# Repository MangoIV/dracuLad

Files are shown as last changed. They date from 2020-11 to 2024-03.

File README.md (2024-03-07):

# The DracuLad keyboard
This is a 34-36-key-board.
## Features
- 36 keys, two of them can be replaced by rotary encoders making it support 34-36 keys and 2-4 encoders. 
- bright RGB Underglow with WS2812b LEDs
- one SSD1306 OLED per side
- support for the [pimoroni trackball](https://shop.pimoroni.com/products/trackball-breakout)
- powered by QMK-firmware (Firmware has been merged and can be found on [the QMK master](https://github.com/qmk/qmk_firmware/))
- aggressive pinky stagger similar to the Kyria but with a slightly alternative thumb cluster to raise comfort for large hands
- support for MX and Kailh choc v1 switches
- files for fr4 plate and acrylic bottom plate as well as OLED window

## State of the project
- PCBs are fully working (OLED, LEDs, all switches, encoders, Trackball)
- acrylic plates have arrived and fit perfectly
- 3D-printable case has been added thanks to the awesome work of Sadek Baroudi
- basic ZMK Firmware (not all features implemented yet) exists on [my fork of the zmk firmware](https://github.com/MangoIV/zmk.git)

## Hardware availability
- hardware availability is always a big problem and ordering everything yourself is a big hustle. Therefore I'm happy to tell you that Ben from keycapsss (not me) is so kind [to offer everything to make a full build](https://keycapsss.com/). And for those of you who are American, [littlekeyboards](https://www.littlekeyboards.com/) (also not me) also offers kits
- if you live in a remote area resulting in high shipping costs or problems with importing, gerbers for ordering the PCBs and SVGs for getting plates cut are available in this repo, too

## Things to consider before getting a DracuLad
- for the upper encoder you can't use the really big guitar knobs as they're too wide and will interfere with the OLEDs, the smaller ones are recommended
- the thumb cluster is lower than on boards like the Corne keyboard
- liking or disliking a layout is not a matter of how "good" the layout is but mostly preference, hence I recommend looking at [a split keyboard comparison site](https://jhelvy.shinyapps.io/splitkbcompare/) and print out some layouts to confirm you like it. (DracuLad can be found there, too)
- before purchasing encoders, make sure they fit! The holes in the plate are 12mm x 12mm and won't fit bigger encoders. They're in particular not the size of the switch footprints.

## Some pictures to get your mouth watery
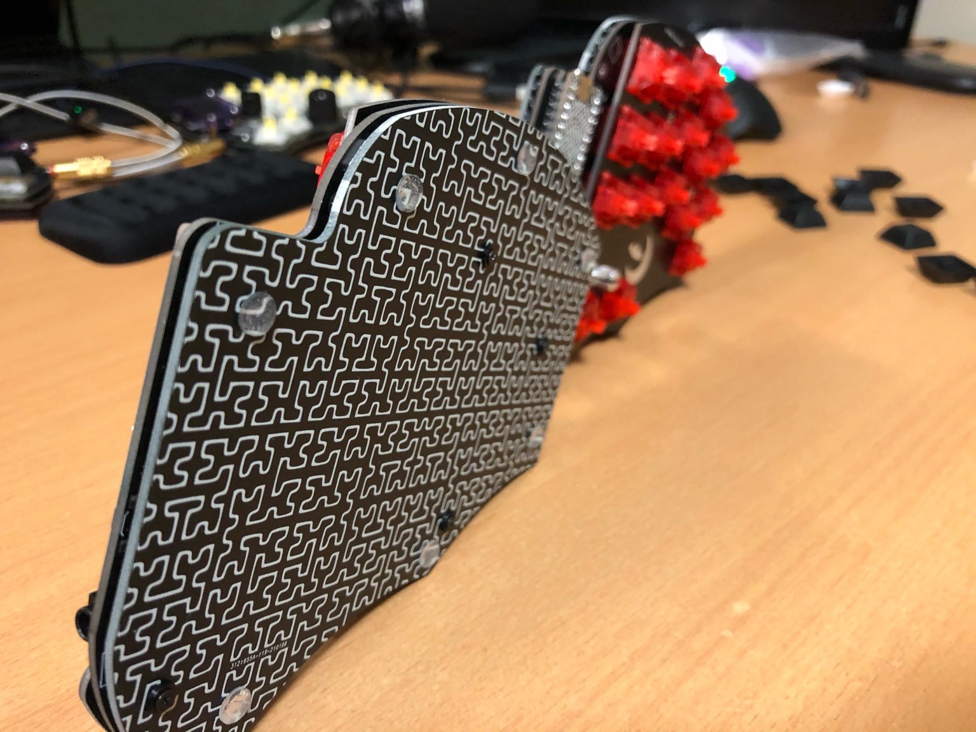
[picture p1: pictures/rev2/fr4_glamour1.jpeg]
glamour shot 1 pimoroni, fr4

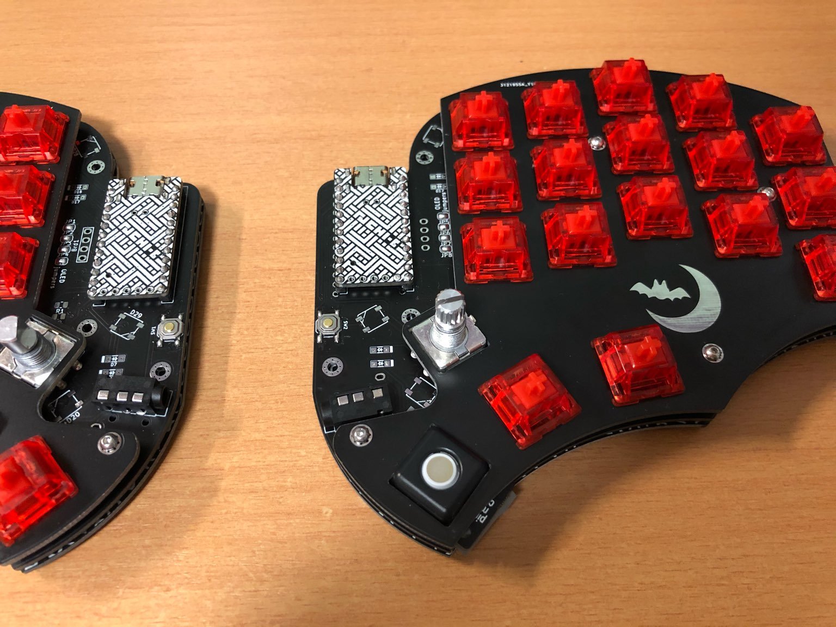
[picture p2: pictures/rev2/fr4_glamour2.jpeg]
glamour shot 1 pimoroni, fr4

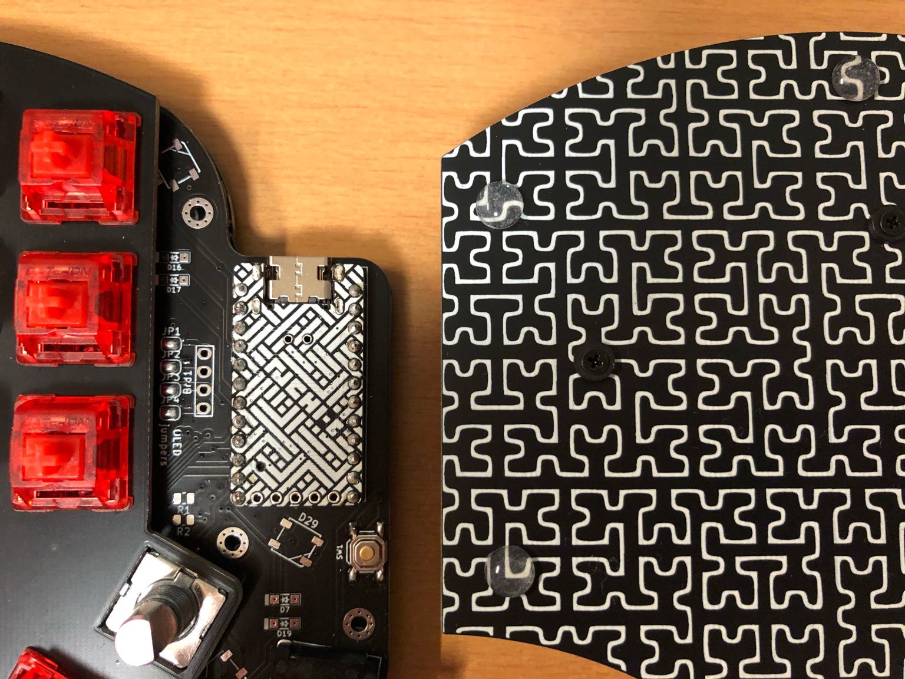
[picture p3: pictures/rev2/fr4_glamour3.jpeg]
glamour shot 1 pimoroni, fr4

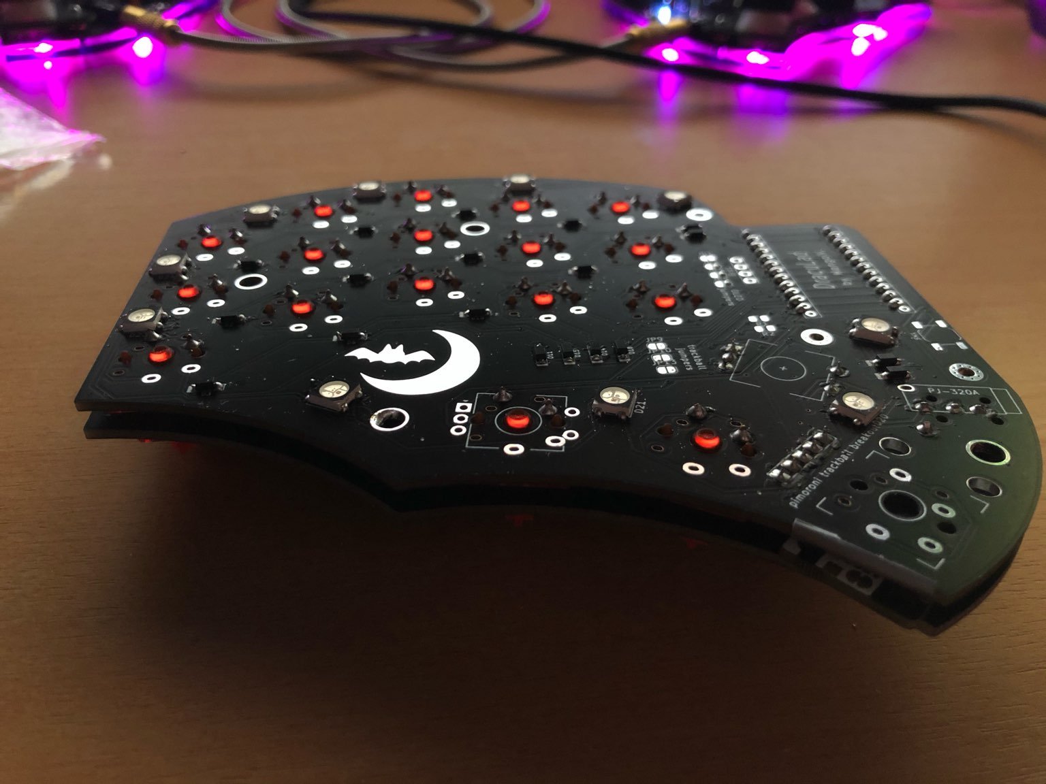
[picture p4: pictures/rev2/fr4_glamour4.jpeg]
glamour shot 1 pimoroni, fr4

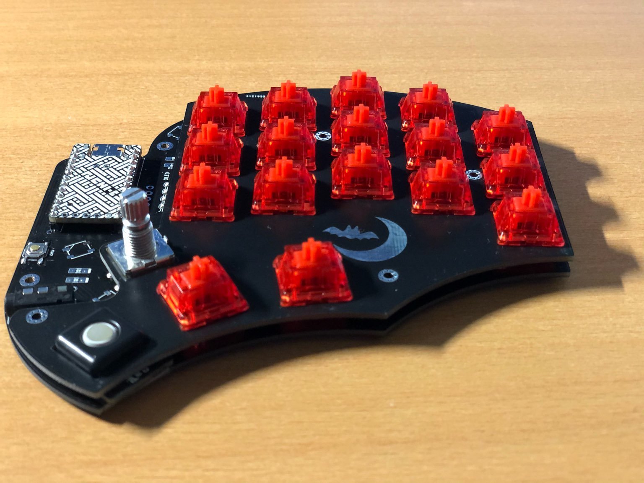
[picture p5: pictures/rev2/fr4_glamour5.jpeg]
glamour shot 1 pimoroni, fr4

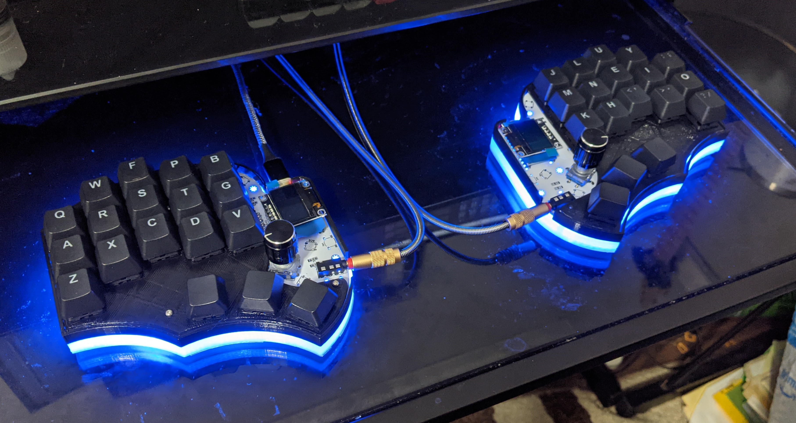
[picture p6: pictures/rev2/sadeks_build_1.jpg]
glamour shot of 3D printed High Pro case by Sadek Baroudi

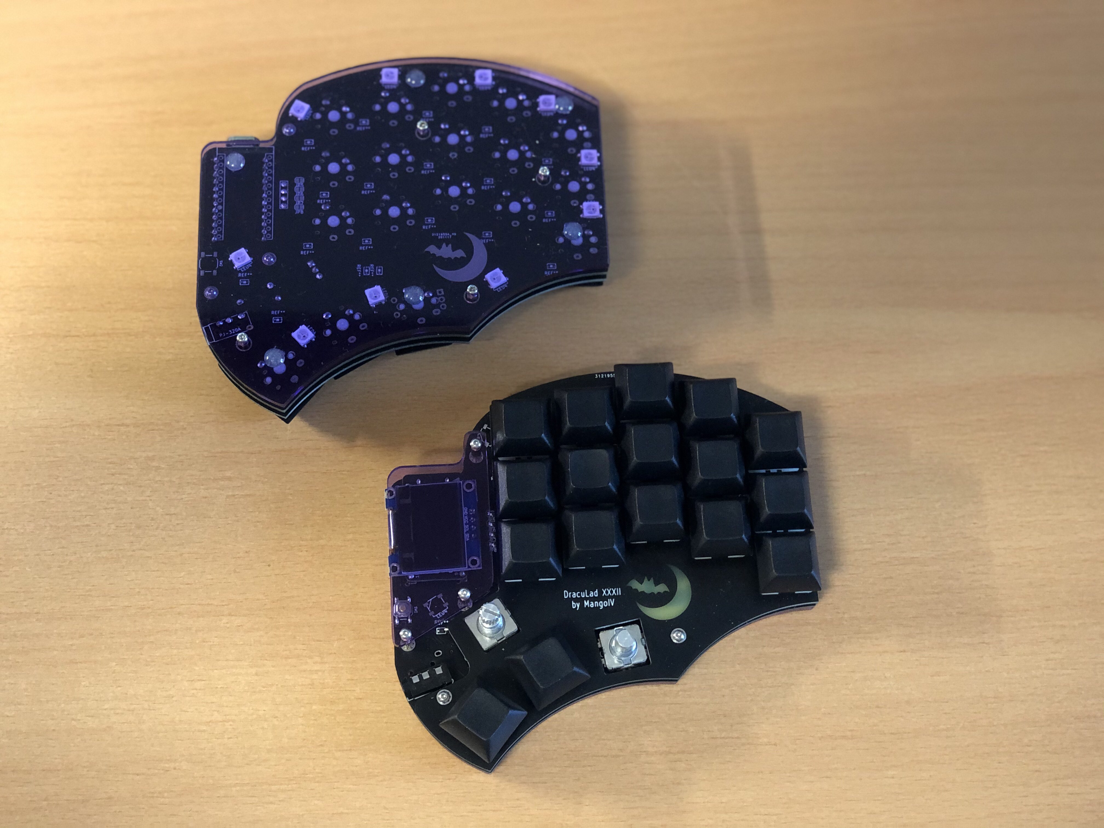
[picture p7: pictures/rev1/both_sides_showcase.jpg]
showcase of both sides

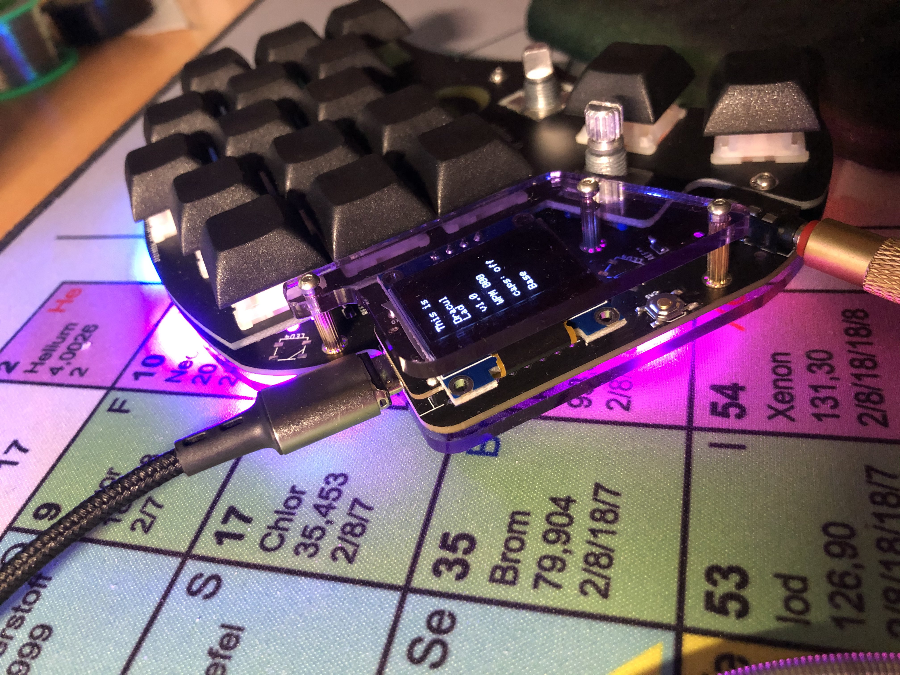
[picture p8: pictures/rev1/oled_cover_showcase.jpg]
showcase of oled cover

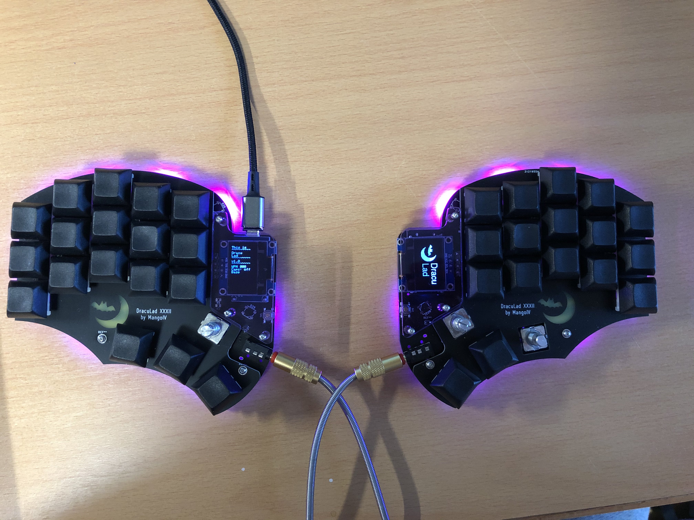
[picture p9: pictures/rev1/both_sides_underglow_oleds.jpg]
showcase of underglow

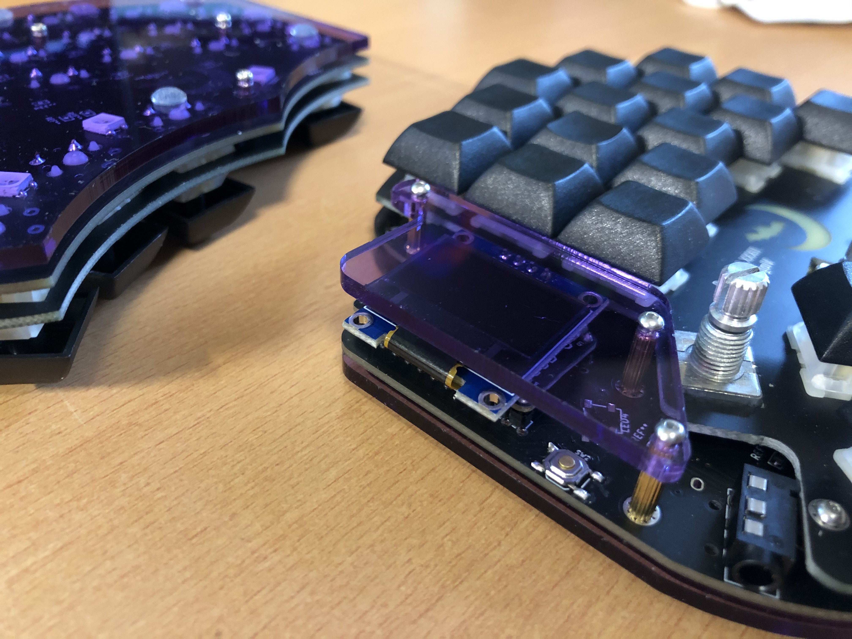
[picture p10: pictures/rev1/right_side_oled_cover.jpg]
oled cover


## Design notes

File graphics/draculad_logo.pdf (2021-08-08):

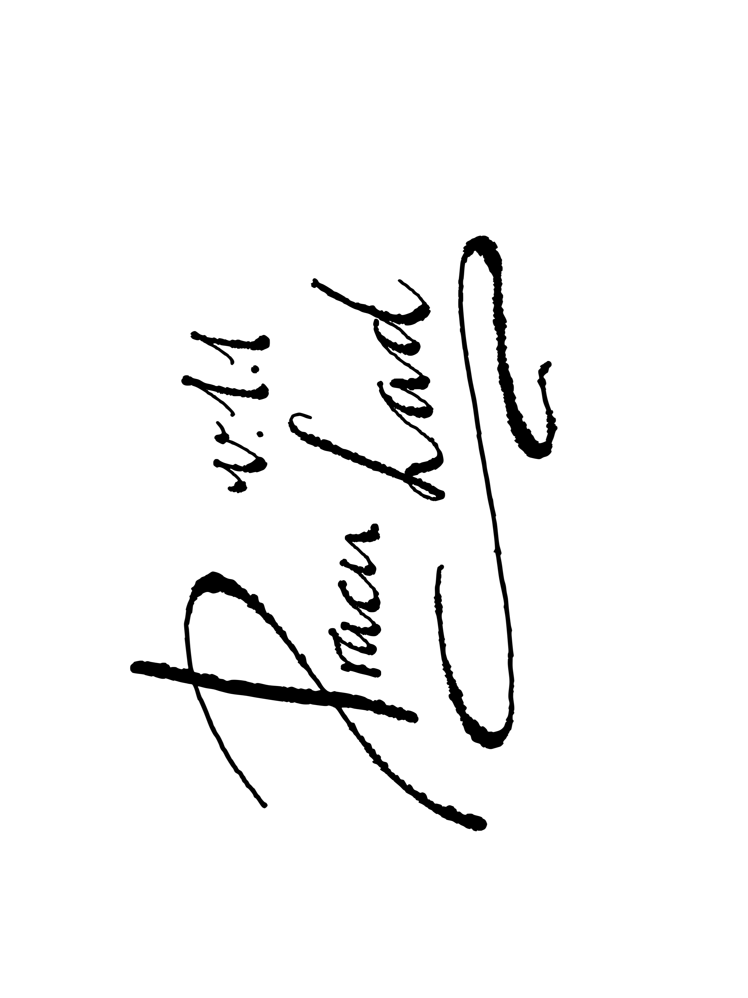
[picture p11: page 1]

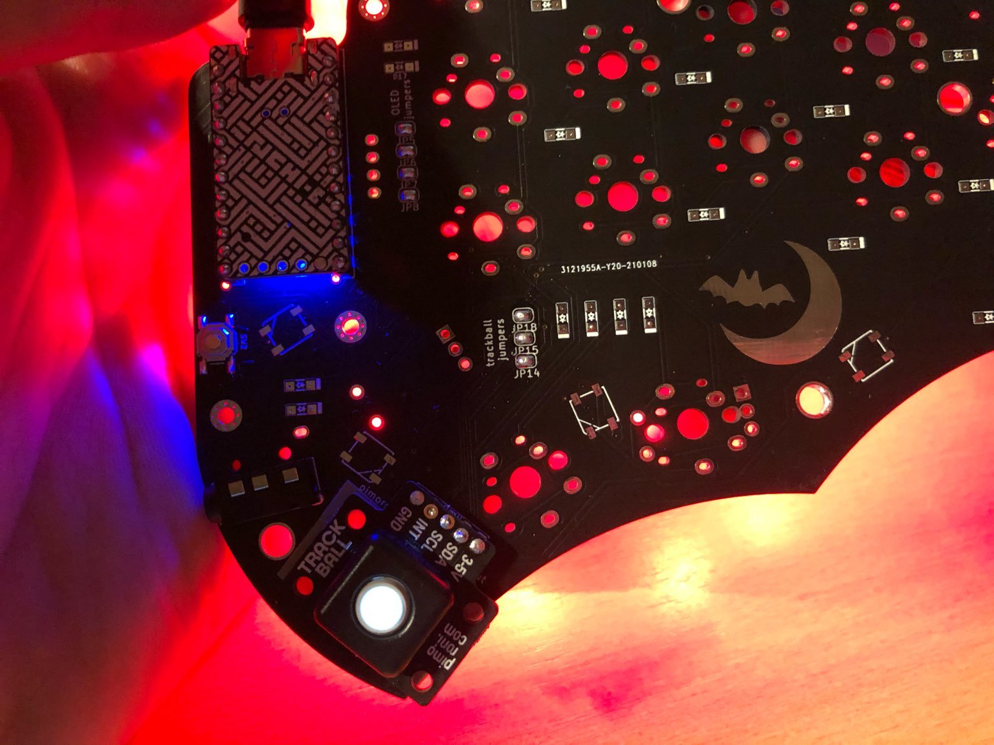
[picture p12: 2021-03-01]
pictures/rev2/fr4_trackball.jpeg

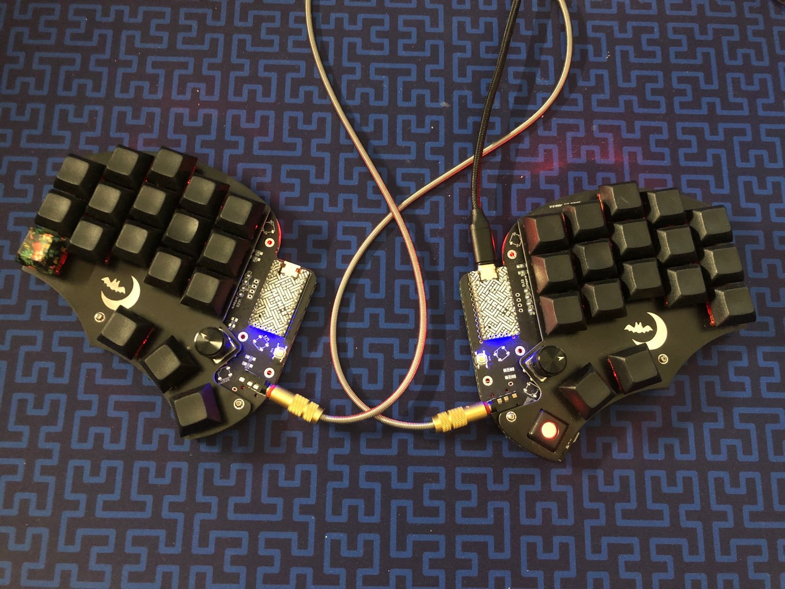
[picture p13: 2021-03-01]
pictures/rev2/rev2_trackball_top.jpeg

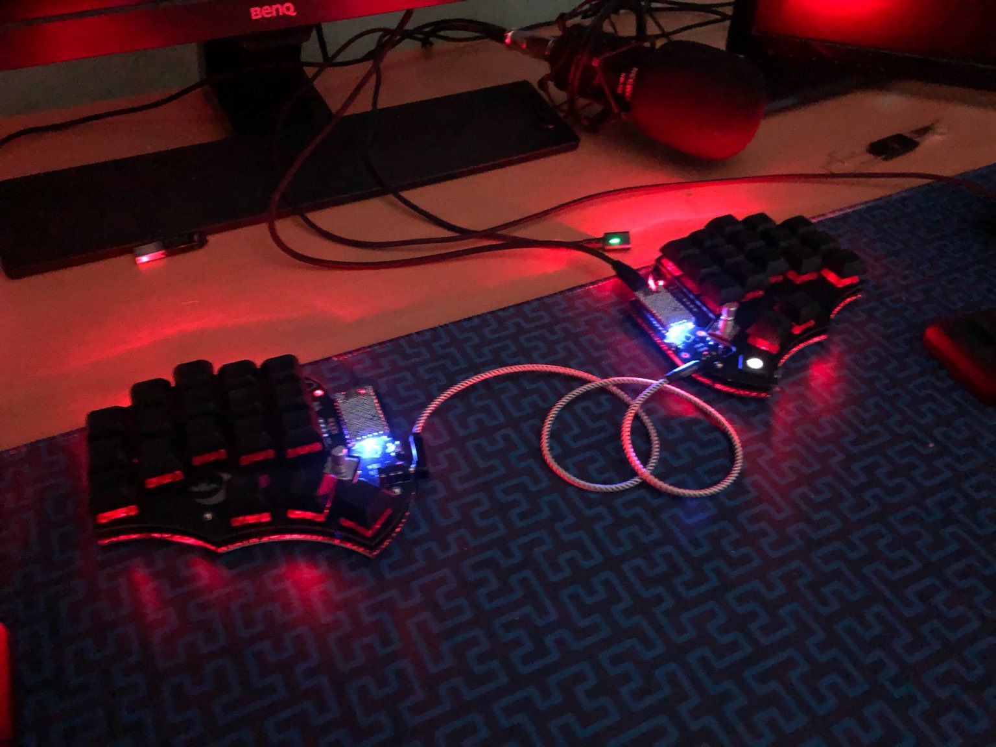
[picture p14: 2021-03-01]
pictures/rev2/fr4_underglow.jpeg

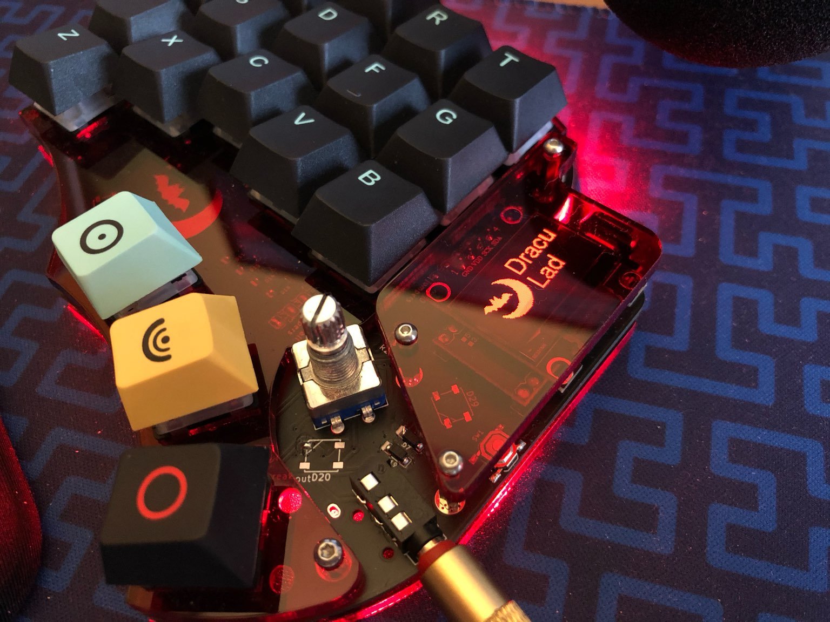
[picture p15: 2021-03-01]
pictures/rev2/acrylic_window_OLED.jpeg

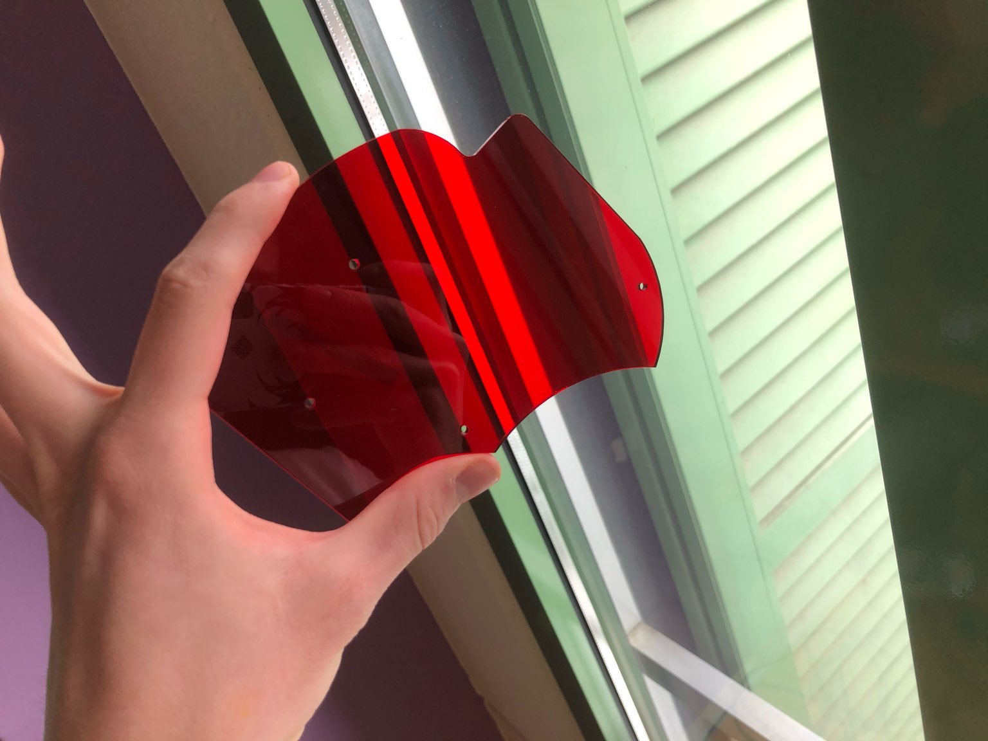
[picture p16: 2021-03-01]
pictures/rev2/acrylic_bottom_plate.jpeg

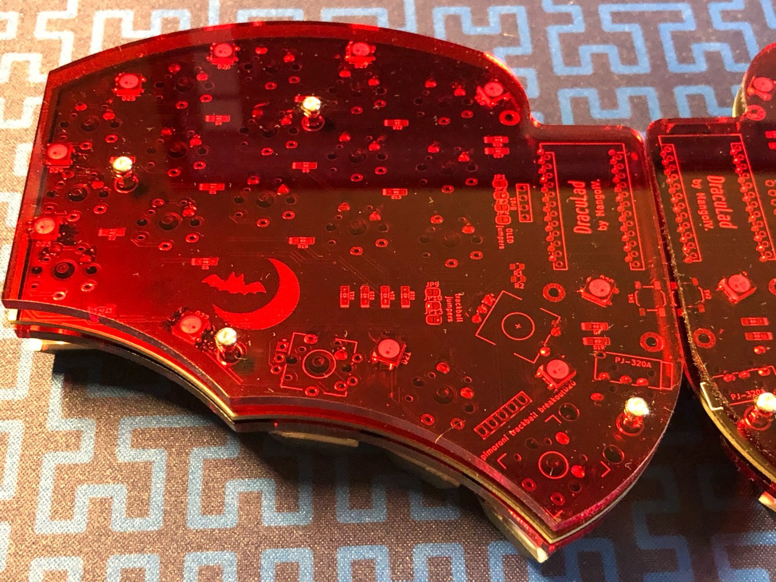
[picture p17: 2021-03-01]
pictures/rev2/acrylic_bottom_right.jpeg

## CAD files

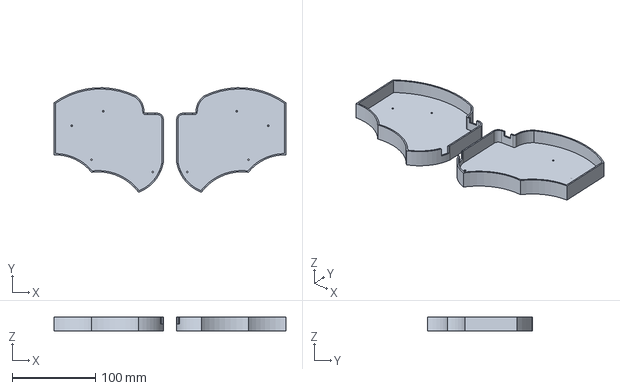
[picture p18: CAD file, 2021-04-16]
case/draculad-case.step
279.1 x 125.8 x 17.0 mm

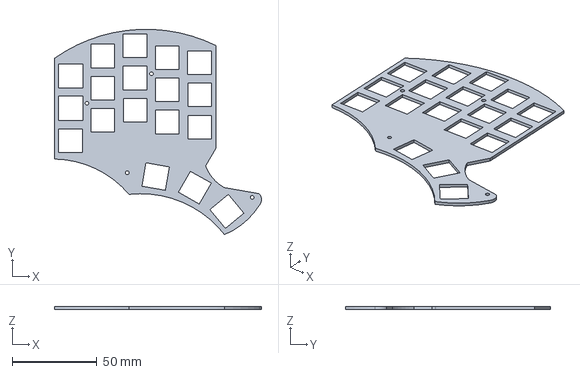
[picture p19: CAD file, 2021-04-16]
case/draculad-split_3x_plate.step
122.2 x 121.2 x 1.60 mm

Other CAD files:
case/draculad-case.f3d
case/draculad-case.stl
case/draculad-split_3x_plate.f3d
case/draculad-split_3x_plate.stl

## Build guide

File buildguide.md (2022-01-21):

# DracuLad Build guide
## What you need
- 2x pcbs
- 2x bottom plate, 2x top plate
- 34-36 switches, either choc low profile v1 or mx compatible ones
- 2 rotary encoders
- 2x pro micro compatible controllers
- 38x sod123 SMD diodes
- 2x reset switches
- 2x TRRS jacks
- 8x 0.7cm standoffs, 16 m2 screws to mount the case 
- usb cable, trrs cable, rotary encoder knobs, keycaps

## What you optionally need
- 2x extra rotary encoders (for the thumb cluster, each additional rotary encoder decreases the needed switchcount by one)
- 20x ws2812b LEDs (if you want underglow)
- 2x SSD1306 OLEDs (128x64)
- 2x OLED cover
- 6x standoffs with m2 screws for the OLED cover (standoff size depends on whether you use the OLEDs or not and probably also how low profile your pro micro is mounted (bit-c for example is a bit higher profile), with OLEDs 1cm is ok)
- 1x pimoroni trackball (this will only fit for the plateless build or the one with the FR4 plate)

## First step: solder the Diodes
- the diode mark should be aligned with the mark on the PCB
- solder the diodes on the bottom of the PCB, the PCBs are reversible, therefore you need to decide for one side in the beginning 
- put solder on one of the pads, reflow the solder while sliding the diode into place, solder the second side of the diode

## Second step: solder the LEDs
- the little triangle on the LED should allign with the triangle on the PCB
- do it similar to the diode, first solder one pad, slide in the LED, solder the other 3 joints
- be careful, those things are really heat sensitive, only ever touch the metal part with the iron, never the plastic - if possible, don't touch the LED with the iron but let the solder flow onto the joints

## Third step: install the pro micros
- before installing the pro micro, flash it with the right firmware which can be found on the [qmk master](https://github.com/qmk/qmk_firmware) or, if you're using a bluetooth controller like the Nice!Nano or the nRFMicro, refer to my fork of the zmk firmware which should implement some basic features on the "draculad"-branch.
- the pro micro headers/sockets should be in the outlines marked on the PCB
- if you need help socketing your controller or never did it before, refer to [this section of the crkbd buildguide](https://nicedoc.io/foostan/crkbd/blob/master/corne-classic/doc/buildguide_en.md#use-socket-to-mount-promicro)
- I strongly recommend socketing your pro micros or pro micro clone
- for reference on how to install your pro micro please look at the [crkbd buildguide](https://nicedoc.io/foostan/crkbd/blob/master/corne-classic/doc/buildguide_en.md). 
- now is the right time to plug in your keyboard and check whether everything works - if you did everything right, every switch - besides the ones that switch layers (refer to the layout in the firmware) - should give you a feedback and all the LEDs should light up red. The LEDs are daisy chained, so check them by correcting them one by one in the chain that starts at the bottom of the pro micro and follows all around on the edge of the PCB

## Fourth step: Install your Pimoroni, OLEDs, Encoders
- for the OLEDs, jump the OLED jumpers on top of the PCB and solder in the OLEDs. Add some insulating tape on the bottom of the OLED to avoid shorts with the pro micro, after that just solder them in, there's not much you can do wrong here
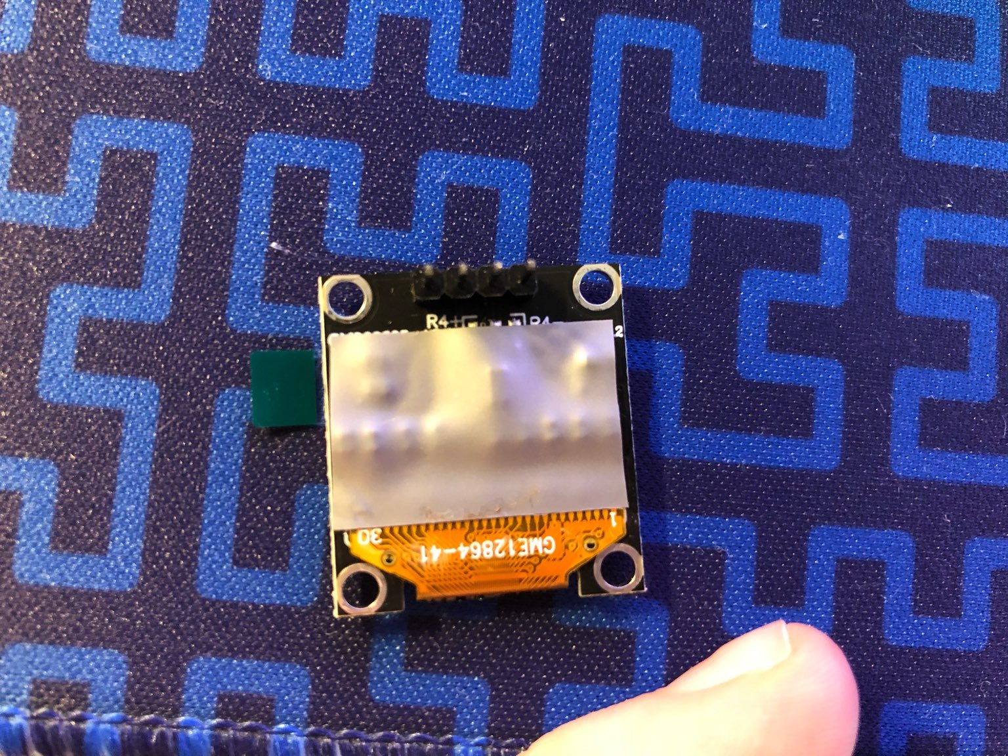
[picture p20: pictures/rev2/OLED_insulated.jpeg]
OLED with insulation tape on bottom


- test them by pluggin in, they should both come on
- for the pimoronis you should not compile the default keymap but rather the "pimoroni" one 
- jump the pimoroni jumpers on top of the PCB
- before soldering the pimoroni, make sure you insulate it with a bit of insulation tape
- solder the pimoroni in
- the pins should be as flush as possible with the top of the pimoroni pcb
- the pimoroni pcb should be parallel to the draculad pcb
- to optimise the profile, use diode pins to connect the pimoroni to the pcb
- after plugging in, your trackball should light up red and work now 
- clip away the short, thick legs of the encoder (!NOT THE PINS!) and solder them into the spots you want them
- remember, all 4 encoder spots are supported at once

## Fifth step: Take a break
At this point you should have a fully working keyboard barebone. Test the encoders and whether there are any errors plugging in the keyboard. Both OLEDs should work, as well as the LEDs and the Pimoroni.
If not, try to correct your mistakes, don't lose your temper, most of the things can be corrected very easily.
If you're debugging your keyboard under Linux, you can test the keys and the encoders by using ```xev -event keyboard``` and whether the keyboard is correctly recognised with ```dmesg --follow -H```. (Mind that you need proper rights to run this command.) 

In the improbable case you're using nix, you can get the keyboard tester with 

```nix
nix-shell -p "xorg.xev" --run "xev -event keyboard"
``` 

## Sixth step, solder in the switches
- depending on whether you build it with or without plate, stick the switches through the plate and then through the pin holes. Solder the pins. 
- mount the OLED cover, use the longer standoffs for that
- screw the shorter standoffs to the switch plate and then to the bottom plate
- mount keycaps
- have fun tinkering with qmk (or zmk)

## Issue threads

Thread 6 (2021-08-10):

Pimoroni firmware

hyphonetics, 2021-08-10:
So I built the keyboard and it works except for the trackball that I have on the right side of the board. When I plug in only the right half, the pimoroni works fine, but when I link that to the left half and use the left as the master side it doesn't function.
I saw in the keymap something about commenting out part of the code on the side without the trackball but I'm not sure what exactly I need to do to get it functioning properly, any help would be greatly appreciated.

MangoIV, 2021-08-10:
Hi! Using the pimoroni trackball on the slave side is not currently supported by the upstream qmk firmware. However, it is possible to implement a custom transport which allows it to use it on the slave side. I'd recommend to ask drashna about it, who did this already.
I hope that resolves your question!

hyphonetics, 2021-08-10:
Awesome, that helps a lot. "Not currently supported" makes me feel better about it not working, I'm glad it wasn't just something I was missing. I may just make the right side my master and change the matrix/keymap in the firmware.
Appreciate the help, thanks for making such an awesome looking little split board as well!

MangoIV, 2021-08-10:
Glad you like it, enjoy your board!

Closed 2021-08-10.

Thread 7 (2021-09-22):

Clearer documentation, maybe with pictures?

jpabst, 2021-09-22:
This is my first keyboard build, and maybe that's the problem... but I'm familiar with soldering etc..

the pinout isn't clear, so I didn't know the right orientation to put in my Elite-C.  Thankfully there's a picture for one side which helped (your not-elite-c that you feature isn't helpful since it doesn't show the pinout on it at all)

Your instructions state to solder in the diodes on the bottom, but it isn't clear where to solder the leds?  Is that also the bottom?
You have pictures: acryli_no_caps_top.jpeg that show the diodes soldered to the top?!?!?

I didn't know to be careful about aligning the pins inside the square indicator for the controller, so I've got them on the wrong pins for one of my PCB's (so I'll unsolder it and move it, but it'll be painful).

The main issue I have right now:  my LEDS won't turn on.  I put them on the top, but I'm guessing that's wrong.  I tried putting one on the bottom of the other board... but while it flashed green briefly (when pressed to the contacts), after I soldered it in... it won't turn on at all (note, that's the only one I had put in.

Also, you have pictures of the OLED jumpers filled in without the OLED being installed (acryli_no_caps_top.jpeg), also have pictures of the trackball jumpers filled in... but no trackball.  So I'm not sure whether I'm supposed to fill them in or not (I don't have the trackball... yet)

MangoIV, 2021-09-22:
Hi!
First off, I want to tell you that this is a more advanced project, targeting mainly people who already built a keyboard and/or have a little bit of experience with that kind of hardware. Many of your questions could be answered looking at the kicad schematic, for example or by common sense. However, I admit that the documentation is a bit sparse and I could do something about that. Now to your questions:
- The orientation of the controllers is always with the MCU facing towards the PCB if you put your pinheaders in the outlined spots on the PCB, you can also match the obvious GND pins (they have little crosses around them) with the GND pins on the controller, if you're unsure
- On the picture the diodes might be soldered on top, this is absolutely possible, as you can clearly see, the under- and topside are connected by Vias within the pads. Soldering them on the bottom is recommended for the simple and practical reason that it is easy to reach, even after soldering in the switches.
- it doesn't really matter whether you put the LEDs on the top or the bottom, they should work in any way. However, they are obviously intended to be soldered on the bottom side, they're for underglow, after all. If you face issues with the LEDs, check them one by one, they are daisy chained. The first LED in the chain should be the one directly under the controller and the other ones just follow in a line. It is quite probable you killed them, they're made of plastic and very sensitive to heat. As a tip, never touch the plastic but always touch only the pins/pad.
- The jumpers can be soldered, even if you don't plan to use an OLED or trackball at that time. It's crucial to solder them on the side the ball/OLED is going on, though, the jumpers basically serve as a way to make the PCB reversible by reversing the pinout corresponding to the jumpers you solder

On a side note: This is an open source project and only a hobby of mine. I am neither responsible for providing a perfect buildguide (although that would be optimal) and neither for other peoples builds. I try to provide as much support as possible but it's not an obligation of mine to do so.

I hope you get your build to work and I'd be happy about a contribution to the buildguide!

Kind regards.

jpabst, 2021-09-23:
Sorry if I came across as demanding, it was late and I was a little frustrated.  I actually went through the different project folders and while it may have given me the pinout in the kicad schematics, I have no idea what kicad is...  I was thinking this morning that I should just put in a pull request with what would have helped me.  the LED's I put on the bottom of the right-hand side work great, it's just the ones on the left-hand (that I did first) that are all probably broken, since desoldering them is tricky and I probably broke them in the process.  Still, the keyboard works!

Thanks for this honestly.  I was looking into the Kyria but supply was a problem for me and I stumbled across this one that had the similar aggressive pinky offset and dove in.

Thanks for the answers and your time

-Jon

MangoIV, 2021-09-23:
Hi,
Just opening that up for a second again to remind you that the LEDs might not all be broken but just a few. Remember, they are daisy chained...

I wish you good luck and great fun with your build and hope you'll get everything working soon!

Closed 2021-09-23.

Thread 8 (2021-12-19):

total newbe help'on how to build the gerber

lpanebr, 2021-12-19:
hi, I love this layout but I don't know which of the pcb files I need to open in kicad to create the gerber file.

any tips???

thanks!

MangoIV, 2021-12-19:
The `.pro` files are the kicad project files :)

lpanebr, 2021-12-19:
thanks! I later noticed that the gerbers.zip was already there.
I found a yt video that helped and already placed the order.

Closed 2021-12-22.

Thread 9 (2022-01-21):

Can't get encoders to work

stefanwatt, 2022-01-21:
I'm using the nice!nano with ZMK on my dracuLad.
Everythings working fine except for the encoders. The keypress works but the rotary action does not.
I followed the [ZMK docs](https://zmk.dev/docs/development/new-shield#encoders) for enabling encoder support.

MangoIV, 2022-01-21:
Hi!

I'm sorry to tell you, that I did not have time to implement ZMK support yet, so I cannot give you working code.
However, you should be aware that generally, ZMK only supports encoder on the central side, not on the peripheral side.

If you think, this is a firmware issue, please be so kind and visit their discord server, for which you can find a link on their website.

If you think, this is a hardware issue, please be aware that all of the encoders are confirmed working on QMK so it's probably a cold joint or a broken encoder.

In case of the latter, you can reach me on the [40% discord](https://discord.gg/zjZjvNkhpW) or on the [German mechanical keyboard discord](discord.gg/mkd).

Good luck with building the DracuLad, I hope I can help you on the discords or you can find help with the zmk guys :)

brandon-page, 2025-02-24:
@stefanwatt Did you get this working?

stefanwatt, 2025-02-24:
Yes there is a ZMK fork that allows you to use both encoders separately. I'm sure you can find it

Closed 2022-01-28.

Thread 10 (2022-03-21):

It's crucial to solder trackball/OLED jumpers even if you don't plan to them?

lpanebr, 2022-03-21:
Hi and thank you sooo much for this great layout!

This is my first built and although I had no experience in soldering anything other than two wires together, I'm careful and like to study in preparation for challenges.

I will not add an OLED or trackball now and will use all the 36 switches as keys, so no rotary encoders also.

I've read [your build guide](https://github.com/MangoIV/dracuLad/blob/master/buildguide.md#draculad-build-guide) and every other guide/video I could find on DracuLad layout (very few unfortunately). I was about to just ignore the jumpers until I read your comment on #7:

> The jumpers can be soldered, even if you don't plan to use an OLED or trackball at that time. It's crucial to solder them on the side the ball/OLED is going on, though, the jumpers basically serve as a way to make the PCB reversible by reversing the pinout corresponding to the jumpers you solder.

Then I thought I'd better ask: *What do you mean by "The jumpers can be soldered, even if you don't plan to use..."?*

Well... while reading your build guide I noticed the referenced crkbd link for socketing the controller is broken. I searched and found this https://github.com/foostan/crkbd/blob/main/corne-classic/doc/buildguide_en.md which I believe is it(?).

Reading [this crkbd buid guide](https://github.com/foostan/crkbd/blob/main/corne-classic/doc/buildguide_en.md) I've found the socketing controller information and also the information below (what you know!?).

> To use OLED modules, short circuit the jumper patterns. Only short circuit the front side

Reading this I did not fully understood if I should 1) short circuit as to close each individually, or 2) short circuit them all with each other?

I then inspected the pictures and am pretty positive it's 1: *Short circuit jumpers as to close each one individually.*
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

*Just for some peace of mind could you please confirm:*
 - if it's this what you meant by "it's crucial to solder them..."?
 - in your layout this should be done to each jumper set (OLED and Trackball)?
 - is it possible to add an OLED later on?

Thanks again!!!

PS: I've attached some pictures just because I'm very happy! I've only done one hand diodes and LEDs yet.

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

MangoIV, 2022-03-21:
Generally, if you want to add an OLED, you have to solder the jumpers **on the top side** that say "oled jumpers". You do it just like that for the pimoroni jumpers.

If you don't plan to use the trackball nor oled, you can just leave them unsoldered but it doesn't hurt to solder them if you decide otherwise in the future. I hope this clarifies it.

Nice soldering, looks good! Have fun with your board!

lpanebr, 2022-04-22:
Hi. I've finished but there only there's something weird:
Both sides are flashed. When the left side is plugged in through USB, all switches work but the right side doesn't work at all (except for the Pro Micro green LED that stays on). If I plug the USB into the right side, the switches work as the left side but mirrored.

I've checked continuity from corresponding TRSS jack connections and from them to their corresponding Pro Micro pin and all is good.

The problem is the same with the OLED jumpers connected or not.

I did not try connecting the trackball as you said them don't need to be jumped.

**Any idea of what I could try?**

MangoIV, 2022-04-23:
Have you flashed the eeprom to remember the correct side? If not you can flash a different firmware on each side , one for left and one for right.

lpanebr, 2022-04-23:
Ow no. I've flashed the same hex I compiled from the draculad keyboard and keymap files on the qmk repo!
Are there different keyboard or keymap files?

lpanebr, 2022-04-23:
Hmmm.. I found this and am trying to understand it:
https://docs.qmk.fm/#/feature_split_keyboard?id=handedness-by-eeprom

lpanebr, 2022-04-23:
I had to change `#define EE_HANDS` with `#define SPLIT_USB_DETECT`, recompile and reflash both sides. Now it works!

MangoIV, 2022-04-23:
Awesome. The article you linked was correct and contains all the information you need if you want handedness by eeprom to work ;)

lpanebr, 2022-04-23:
When I finish I'll send a PR to include my keymap to the draculad keyboard layout.

MangoIV, 2022-04-24:
I wouldn't do that. Qmk already includes enough keymaps and the PR will last an eternity to merge. Please don't keep the maintainers busy with things like that, except if your keymap contains something really innovative.

lpanebr, 2022-04-25:
OK.

MangoIV, 2022-04-27:
Do you have any other issues? If not I'd close this ;)

lpanebr, 2022-04-27:
Actually on the left board only two LEDs are working.
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

But I think the cause is probably that I have ruined this one:
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

so I'll just replace it.

Yes, you may close. Thanks for this awesome PCB and for all your support!

Closed 2022-04-27.

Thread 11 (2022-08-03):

e Key Not Registering

ehildebrandtrojo, 2022-08-03:
Hello,

I ordered a dracuLad kit from [littlekeyboards.com](https://www.littlekeyboards.com) and I'm having an issue where the E key is not registering (red circle). I replaced the nearby diode (blue circle) but no luck. I also tried creating a bridge with the nearby keys, but I was unable to get it working.

Once, while fixing the last LED of the right hand side PCB, the e key registered. Unfortunately, I tried the e key after a couple of minutes and it stopped registering.

Do you have any advice as to what could be going wrong/how to fix it? Could it be a manufacturing defect?

Thank you

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

Closed 2023-06-01.

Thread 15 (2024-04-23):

Both rotary encoders are assigned the same functionality in current qmk default keymap

joachimmathes, 2024-04-23:
When I flashed my draculad over a year ago both rotary encoders worked as expected with a customized callback function `encoder_update_user()`. But when I lately switched to the new qmk setup with separated `qmk_firmware` and `qmk_userspace` weird encoder behavior occurred. So I tried the `default` keymap with
```
qmk flash --keyboard draculad -km default
```
on commit https://github.com/qmk/qmk_firmware/commit/1fa84ea83c68bb24bc6b21c5abc376ee12d1b939
What happens is, that the left encoder works as expected: VOLD/VOLD. But the right encoder has the mirrored assignment (VOLU/VOLD). According to https://github.com/qmk/qmk_firmware/blob/1fa84ea83c68bb24bc6b21c5abc376ee12d1b939/keyboards/draculad/keymaps/default/keymap.c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 it should trigger PGDN/PGUP.

I haven't found the reason, yet.

Do you run into the same behavior?

natskis, 2024-09-01:
Has this worked for you?
My draculad is doing the same thing.
Just inverting and executing VOLU/VOLD.

I'm wondering if it's because you need to use the split keyboard functions and it's not reading that it's on the right side of the draculad...
I am a total newb at this though so very unsure and a bit confused

https://docs.qmk.fm/features/encoders#split-keyboards

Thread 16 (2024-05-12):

PCB Pinout

brandon-page, 2024-05-12:
Apologies if there is an obvious file with this info but I didn't see it.  Does anyone have a PCB Pinout diagram for the controller?

I would like to use a Seeed Studio XIAO NRF52840, which is shorter than a Pro Micro but a 3x5+3 matrix doesn't take many pins. Since I am going wireless/ZMK I don't care about LEDs or trackball and could live without encoders if I had to. If some of the matrix pins are lower down (where they would be missing on my controller) I could wire jumpers, I would just need to know which pins.

Thanks!

MangoIV, 2024-05-12:
The kicad files are available. They also have the pinout. I don’t think the xiao will be a possibility if I had to guess. Not enough pins.

brandon-page, 2024-05-12:
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

Closed 2024-05-12.

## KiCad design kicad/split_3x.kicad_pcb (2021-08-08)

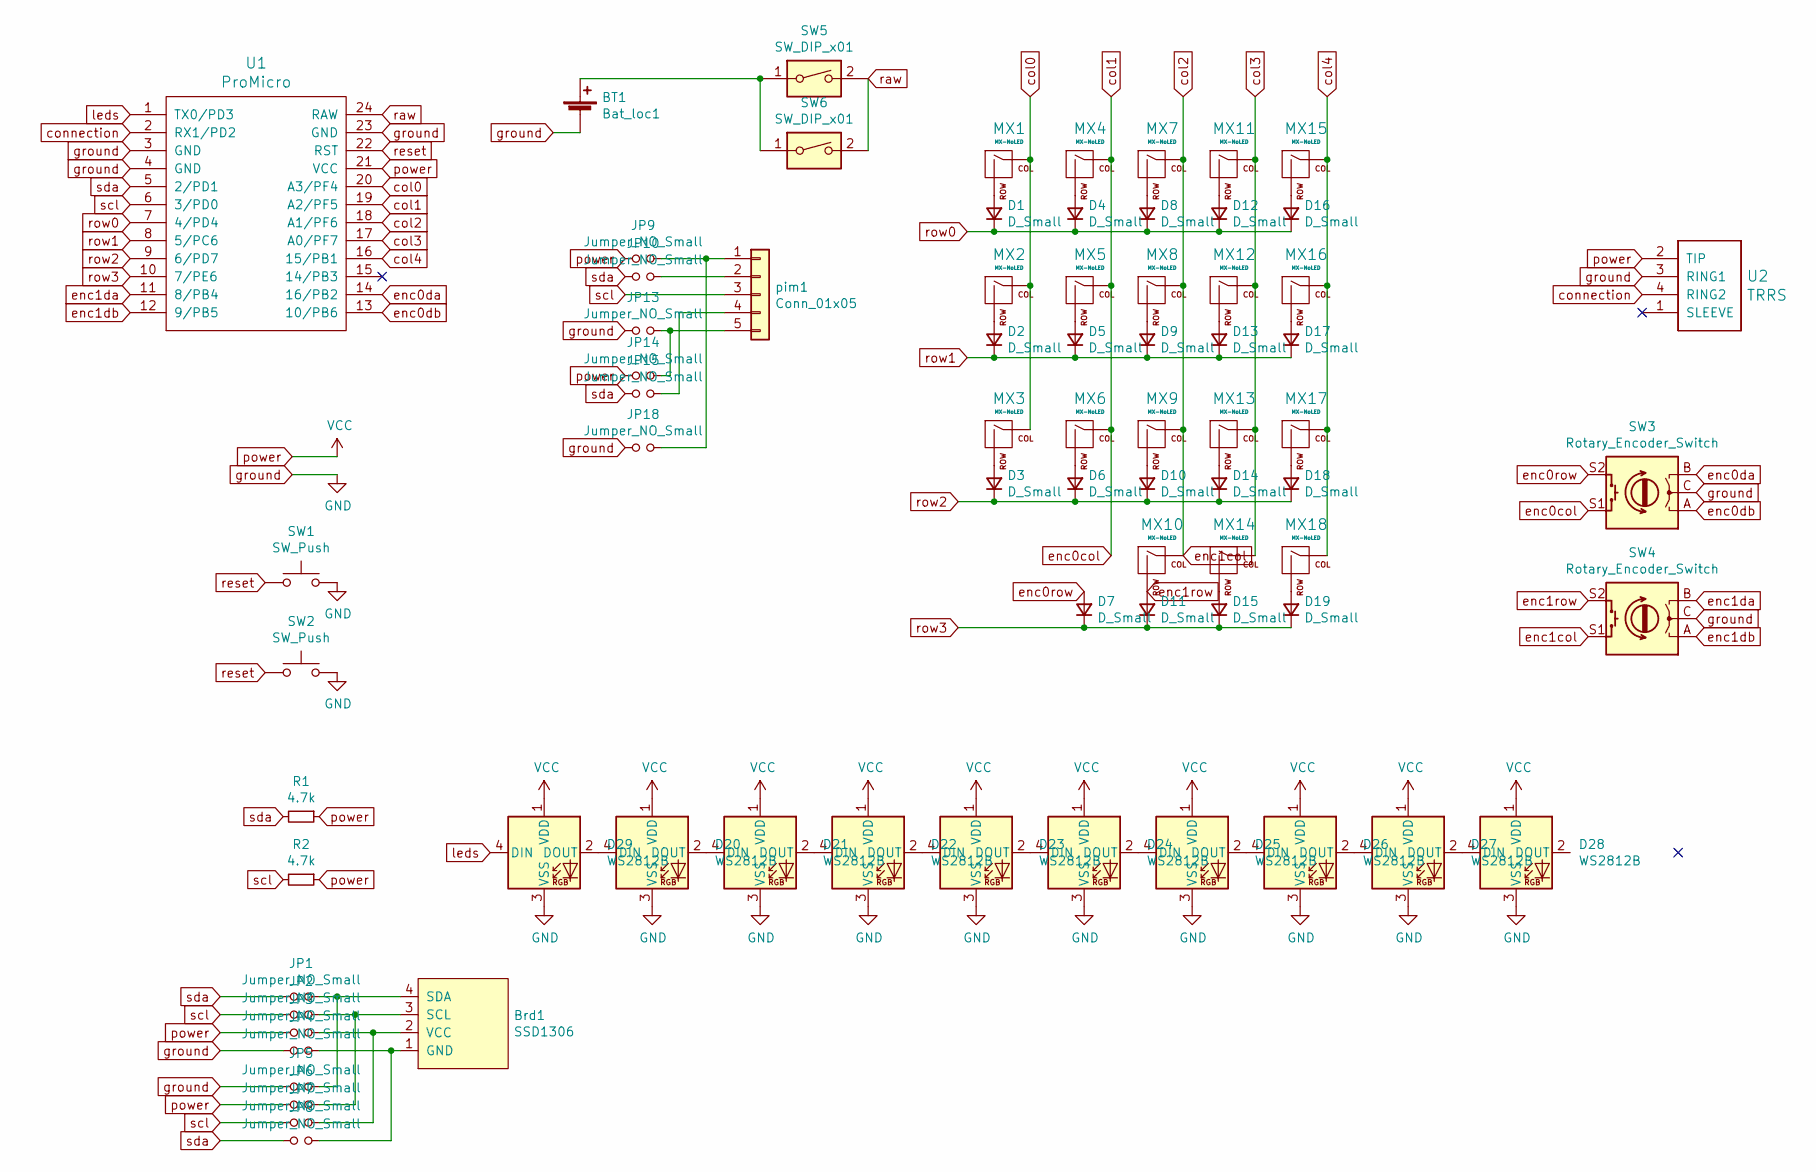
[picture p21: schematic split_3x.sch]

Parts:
BT1: Bat_loc1; PinHeader_1x02_P2.00mm_Vertical
Brd1: SSD1306; 128x64OLED
D1, D2, D3, D4, D5, D6, D7, D8, D9, D10, D11, D12, D13, D14, D15, D16, D17, D18, D19: D_Small; D_SOD123F
D20, D21, D22, D23, D24, D25, D26, D27, D28, D29: WS2812B
JP1, JP2, JP3, JP4, JP5, JP6, JP7, JP8, JP9, JP10, JP13, JP14, JP15, JP18: Jumper_NO_Small; SolderJumper-2_P1.3mm_Open_RoundedPad1.0x1.5mm
MX1, MX2, MX3, MX4, MX5, MX6, MX7, MX8, MX9, MX10, MX11, MX12, MX13, MX14, MX15, MX16, MX17, MX18: MX-NoLED; CherryMX_Choc_1u_reversible
R1, R2: 4.7k; R_0805_2012Metric
SW1, SW2: SW_Push; SW_SPST_TL3342
SW3, SW4: Rotary_Encoder_Switch; RotaryEncoder_EC11-no-legs
SW5, SW6: SW_DIP_x01; switch_MSK-12C02_smd
U1: ProMicro
U2: TRRS; TRRS-PJ-320A-dual
pim1: Conn_01x05; pimoroni_left_side_mount

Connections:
unnamed: BT1.1 (+), SW5.1, SW6.1
unnamed: Brd1.1 (GND), JP4.2, JP8.2
unnamed: Brd1.2 (VCC), JP3.2, JP7.2
unnamed: Brd1.3 (SCL), JP2.2, JP6.2
unnamed: Brd1.4 (SDA), JP1.2, JP5.2
unnamed: D1.2 (A), MX1.2 (ROW)
unnamed: D2.2 (A), MX2.2 (ROW)
unnamed: D3.2 (A), MX3.2 (ROW)
unnamed: D4.2 (A), MX4.2 (ROW)
unnamed: D5.2 (A), MX5.2 (ROW)
unnamed: D6.2 (A), MX6.2 (ROW)
unnamed: D8.2 (A), MX7.2 (ROW)
unnamed: D9.2 (A), MX8.2 (ROW)
unnamed: D10.2 (A), MX9.2 (ROW)
unnamed: D12.2 (A), MX11.2 (ROW)
unnamed: D13.2 (A), MX12.2 (ROW)
unnamed: D14.2 (A), MX13.2 (ROW)
unnamed: D15.2 (A), MX14.2 (ROW)
unnamed: D16.2 (A), MX15.2 (ROW)
unnamed: D17.2 (A), MX16.2 (ROW)
unnamed: D18.2 (A), MX17.2 (ROW)
unnamed: D19.2 (A), MX18.2 (ROW)
unnamed: D20.2 (DOUT), D21.4 (DIN)
unnamed: D20.4 (DIN), D29.2 (DOUT)
unnamed: D21.2 (DOUT), D22.4 (DIN)
unnamed: D22.2 (DOUT), D23.4 (DIN)
unnamed: D23.2 (DOUT), D24.4 (DIN)
unnamed: D24.2 (DOUT), D25.4 (DIN)
unnamed: D25.2 (DOUT), D26.4 (DIN)
unnamed: D26.2 (DOUT), D27.4 (DIN)
unnamed: D27.2 (DOUT), D28.4 (DIN)
unnamed: JP10.2, pim1.2
unnamed: JP13.2, JP14.2, pim1.5
unnamed: JP15.2, pim1.4
unnamed: JP9.2, JP18.2, pim1.1
col0: MX1.1 (COL), MX2.1 (COL), MX3.1 (COL), U1.20 (A3/PF4)
col1: MX4.1 (COL), MX5.1 (COL), MX6.1 (COL), SW3.S1, U1.19 (A2/PF5)
col2: MX7.1 (COL), MX8.1 (COL), MX9.1 (COL), MX10.1 (COL), SW4.S1, U1.18 (A1/PF6)
col3: MX11.1 (COL), MX12.1 (COL), MX13.1 (COL), MX14.1 (COL), U1.17 (A0/PF7)
col4: MX15.1 (COL), MX16.1 (COL), MX17.1 (COL), MX18.1 (COL), U1.16 (15/PB1)
connection: U1.2 (RX1/PD2), U2.4 (RING2)
enc0da: SW3.B, U1.14 (16/PB2)
enc0db: SW3.A, U1.13 (10/PB6)
enc0row: D7.2 (A), SW3.S2
enc1da: SW4.B, U1.11 (8/PB4)
enc1db: SW4.A, U1.12 (9/PB5)
enc1row: D11.2 (A), MX10.2 (ROW), SW4.S2
ground: BT1.2 (-), D20.3 (VSS), D21.3 (VSS), D22.3 (VSS), D23.3 (VSS), D24.3 (VSS), D25.3 (VSS), D26.3 (VSS), D27.3 (VSS), D28.3 (VSS), D29.3 (VSS), JP4.1, JP5.1, JP13.1, JP18.1, SW1.2, SW2.2, SW3.C, SW4.C, U1.3 (GND), U1.4 (GND), U1.23 (GND), U2.3 (RING1)
leds: D29.4 (DIN), U1.1 (TX0/PD3)
power: D20.1 (VDD), D21.1 (VDD), D22.1 (VDD), D23.1 (VDD), D24.1 (VDD), D25.1 (VDD), D26.1 (VDD), D27.1 (VDD), D28.1 (VDD), D29.1 (VDD), JP3.1, JP6.1, JP9.1, JP14.1, R1.1, R2.1, U1.21 (VCC), U2.2 (TIP)
raw: SW5.2, SW6.2, U1.24 (RAW)
reset: SW1.1, SW2.1, U1.22 (RST)
row0: D1.1 (K), D4.1 (K), D8.1 (K), D12.1 (K), D16.1 (K), U1.7 (4/PD4)
row1: D2.1 (K), D5.1 (K), D9.1 (K), D13.1 (K), D17.1 (K), U1.8 (5/PC6)
row2: D3.1 (K), D6.1 (K), D10.1 (K), D14.1 (K), D18.1 (K), U1.9 (6/PD7)
row3: D7.1 (K), D11.1 (K), D15.1 (K), D19.1 (K), U1.10 (7/PE6)
scl: JP2.1, JP7.1, R2.2, U1.6 (3/PD0), pim1.3
sda: JP1.1, JP8.1, JP10.1, JP15.1, R1.2, U1.5 (2/PD1)

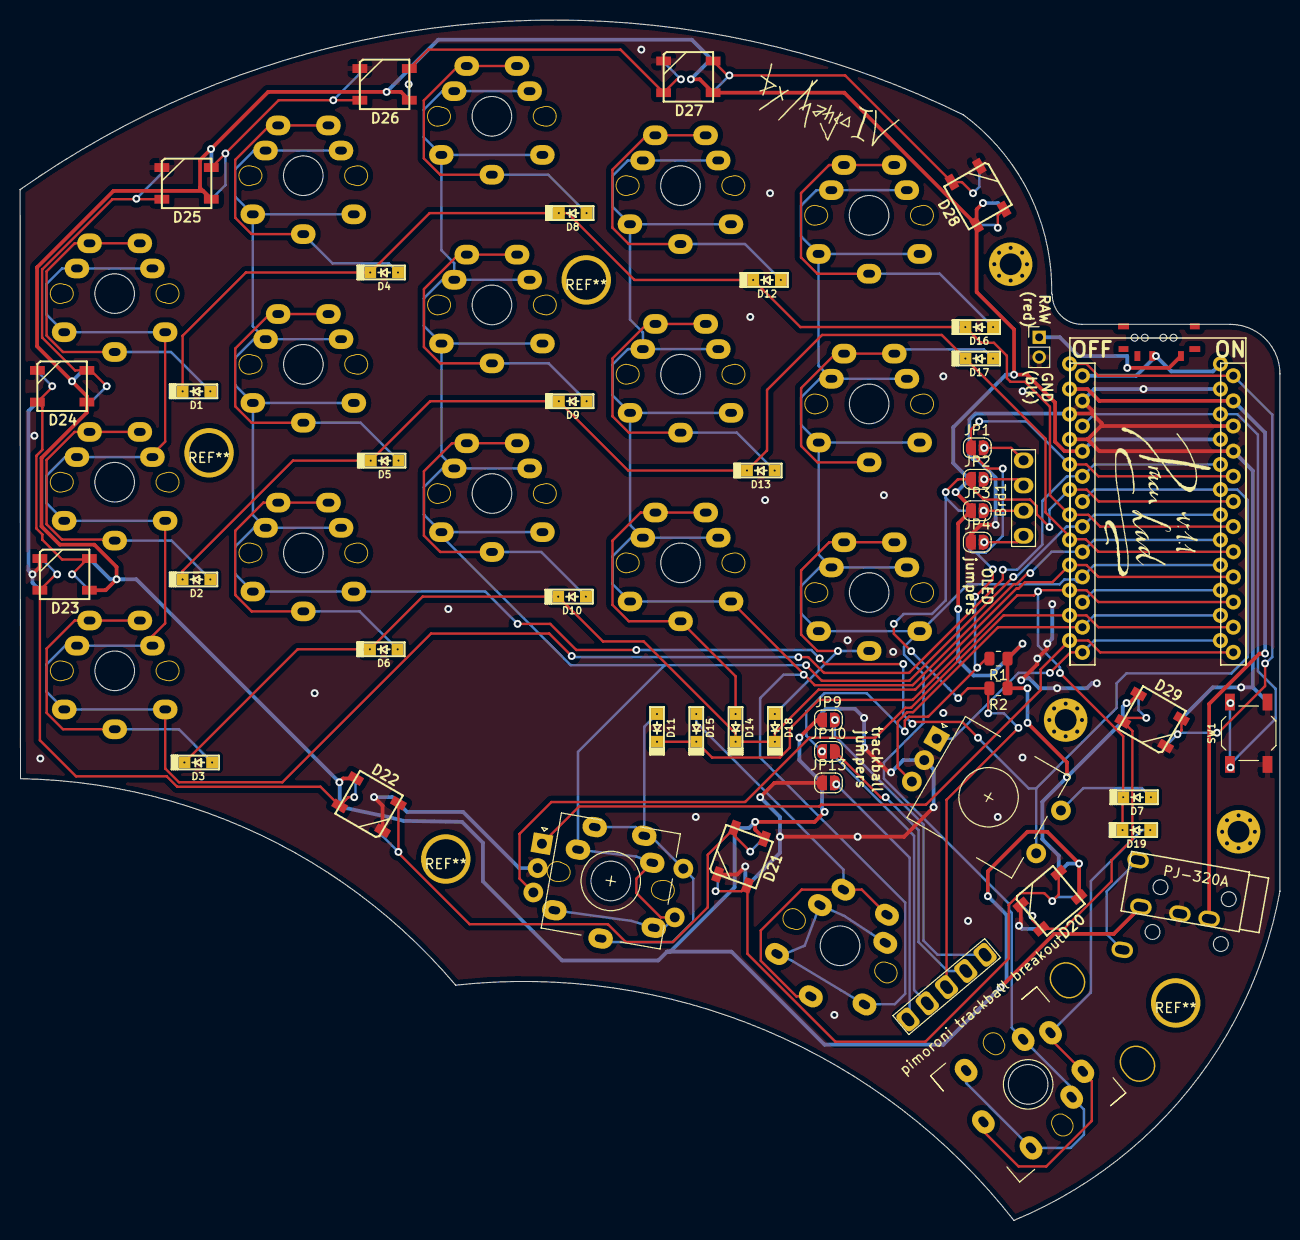
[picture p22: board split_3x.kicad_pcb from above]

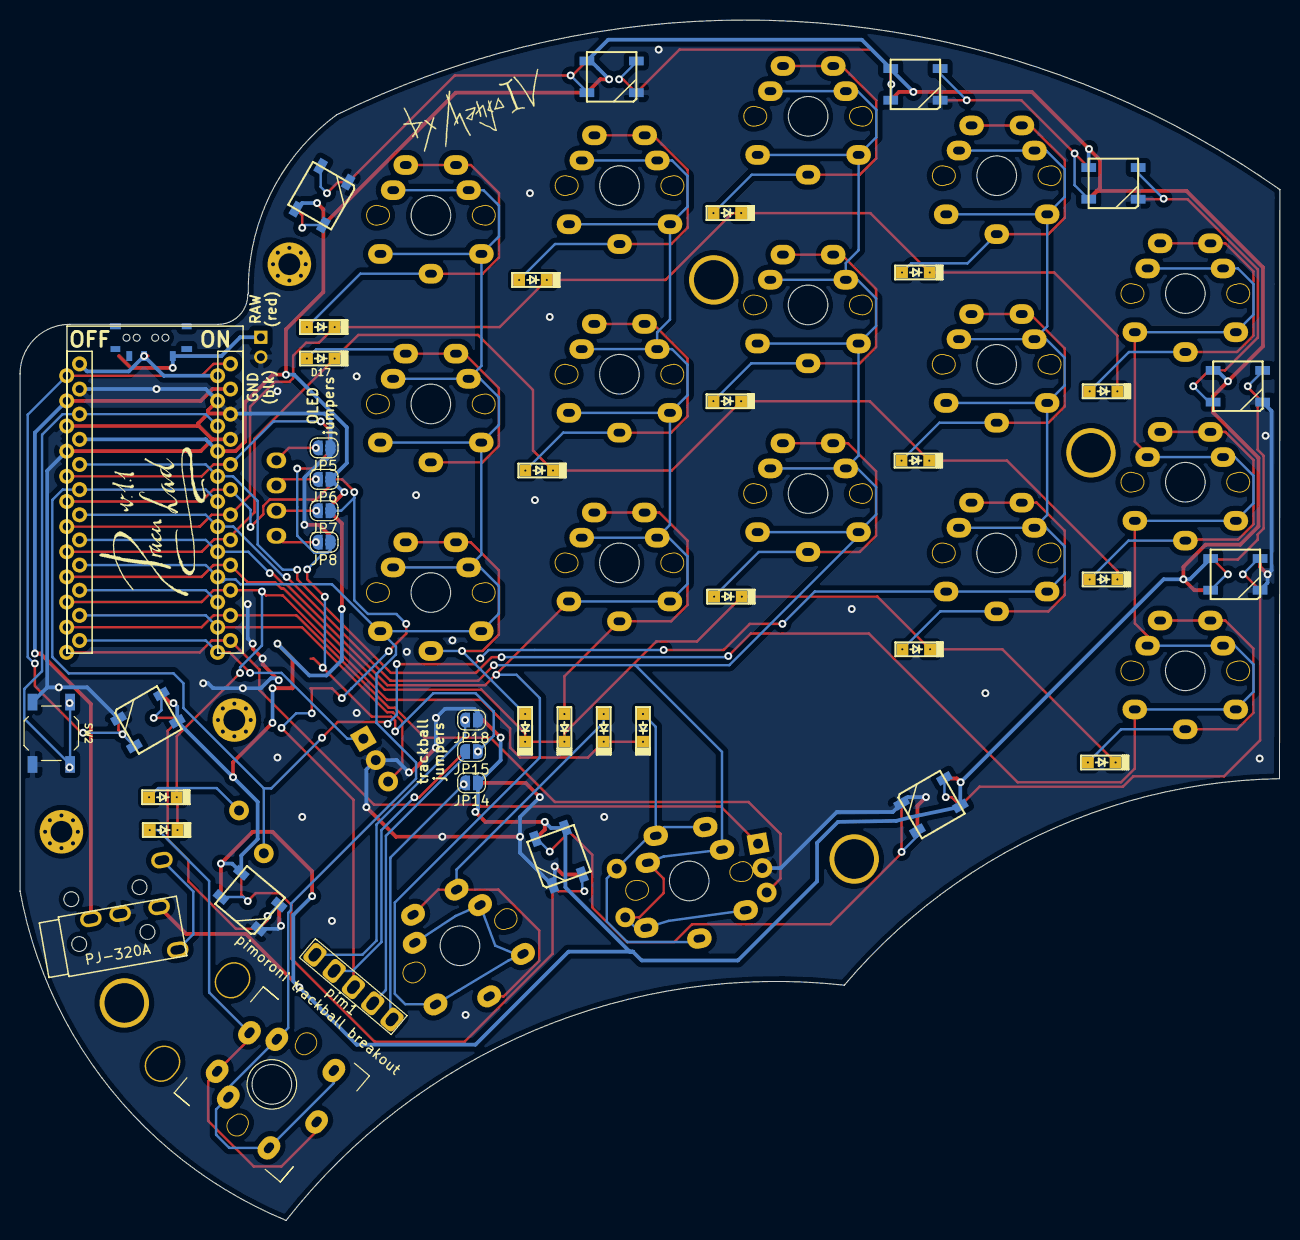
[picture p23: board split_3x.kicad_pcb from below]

Board: 2 copper layers, 127.3 x 121.2 mm, 77 parts (10 on the bottom side), 58 nets.

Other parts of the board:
 : MountingHole_2.2mm_M2_Pad_Via
 #2,  #3: MountingHole_2.2mm_M2_Pad_Via

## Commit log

2020-11-15 created project
    [split_3x.kicad_pcb, split_3x.sch]
2020-11-15 added part of the schematic
2020-11-16 started the pcb
    [split_3x.kicad_pcb]
2020-11-16 replaced some things, added edgecuts
    [split_3x.kicad_pcb, split_3x.sch]
2020-11-16 added some routing
    [split_3x.kicad_pcb, split_3x.sch]
2020-11-16 finished routing
    [split_3x.kicad_pcb, split_3x.sch]
2020-11-16 added art and text
    [split_3x.kicad_pcb]
2020-11-16 added gerbers
    [split_3x-B_Cu.gbr, split_3x-B_Mask.gbr, split_3x-B_SilkS.gbr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]
2020-11-17 added plate
    [split_3x.kicad_pcb, split_3x_plate.kicad_pcb]
2020-11-17 added plate and gerbers
    [split_3x-B_Cu.gbr, split_3x-B_Mask.gbr, split_3x-B_SilkS.gbr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]
2020-11-24 added svg for bottom plate
    [split_3x_bottom.kicad_pcb]
2020-11-30 added pictures
    [split_3x.kicad_pcb]
2020-12-07 changed the plate to have copper pane, updated gerbers of pcb and plate
    [split_3x-B_Cu.gbr, split_3x-B_Mask.gbr, split_3x-B_SilkS.gbr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]
2021-01-05 added support for the pimoroni trackball breakout, changed a bunch of things, rewired the pcb, changed the bottom plate to be prettier, added some silkscreen, changed the position of one of the mount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
    [split_3x.kicad_pcb, split_3x.sch, split_3x_bottom.kicad_pcb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]
2021-01-06 generated gerbers for the second run
    [split_3x-B_Cu.gbr, split_3x-B_Mask.gbr, split_3x-B_SilkS.gbr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]
2021-01-18 dunno when i last pushed therefore I'm commiting
    [split_3x-B_Cu.gbr, split_3x-B_Mask.gbr, split_3x-B_SilkS.gbr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]
2021-01-19 added svg for acrylic plate cutting
    [split_3x_bottom_svg.kicad_pcb, split_3x_plate.kicad_pcb, split_3x_plate_gerber.kicad_pcb]
2021-04-16 Case 3d model with stls, and pictures of the build
    [draculad-case.f3d, draculad-case.step, draculad-case.stl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]
2021-08-05 adde a footprint to solder a battery and smd switches to toggle it
    [split_3x-B_Cu.gbr, split_3x-B_Mask.gbr, split_3x-B_SilkS.gbr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]
2021-08-05 modified the silkscreen to work better with the battery
    :
    [split_3x-B_Cu.gbr, split_3x-B_Mask.gbr, split_3x-B_SilkS.gbr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]
2021-08-05 zipped gerbers
2021-08-05 added plate that is better for large encoder bases
    [split_3x_plate_bigger_encoder_gerber-B_Cu.gbr, split_3x_plate_bigger_encoder_gerber-B_Mask.gbr, split_3x_plate_bigger_encoder_gerber-B_SilkS.gbr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]
2021-08-08 added v1.1 silkscreenart, added mangoiv logo, moved the switch footprint a little bit
    [split_3x.kicad_pcb]
